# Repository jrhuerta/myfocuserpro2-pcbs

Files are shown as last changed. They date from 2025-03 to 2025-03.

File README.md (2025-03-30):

# myfocuserpro2-pcbs

Custom PCBs for the MyFocuserPro2 project.

There are custom PCBs using an Arduino Nano and a driver with the corresponding [MyFocuerPro2 firmare](https://sourceforge.net/projects/arduinoascomfocuserpro2diy/).

DISCLAIMER: I designed and ordered the PCBs just last night, so I haven’t had the opportunity to test them yet. I’ll confirm their functionality as soon as they arrive. Your reviews and pull requests are welcome. As with any DIY project, please proceed at your own risk.

## ULN2003

This version used with the 28BYJ-48 5V stepper powered directly from USB and a simple ULN2003 driver.
Intended to be used with an OAG or Guidescope, with 2 push bottons to retain the ability to adjust the scope manually.

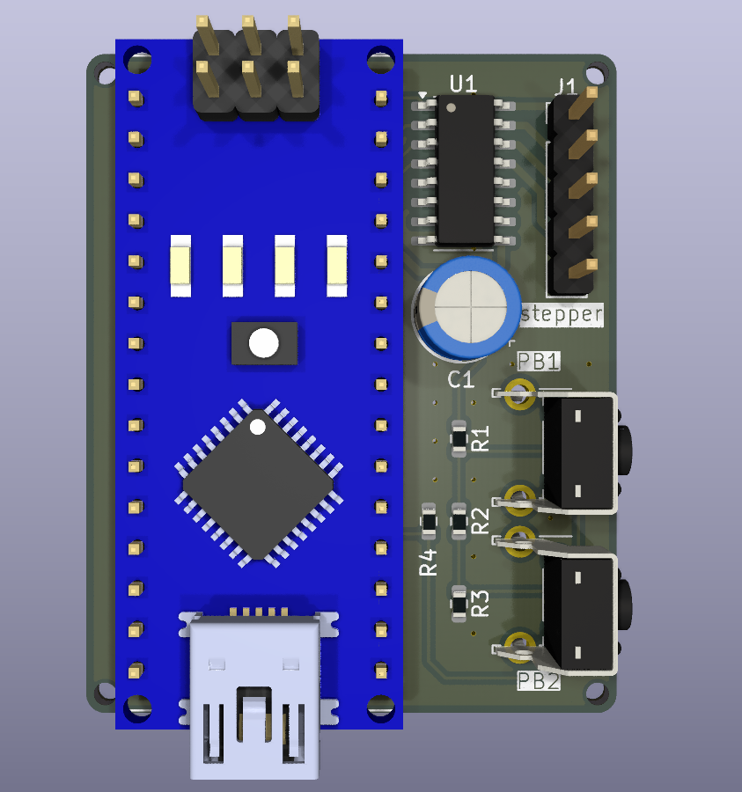
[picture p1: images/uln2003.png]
ULN2003 Driver


## DRV8825

This version is used with a geared Nema17 and external 12V power, intended to handle heavier image trains.
It has the footprint to expand it with a set of push bottons if desired.

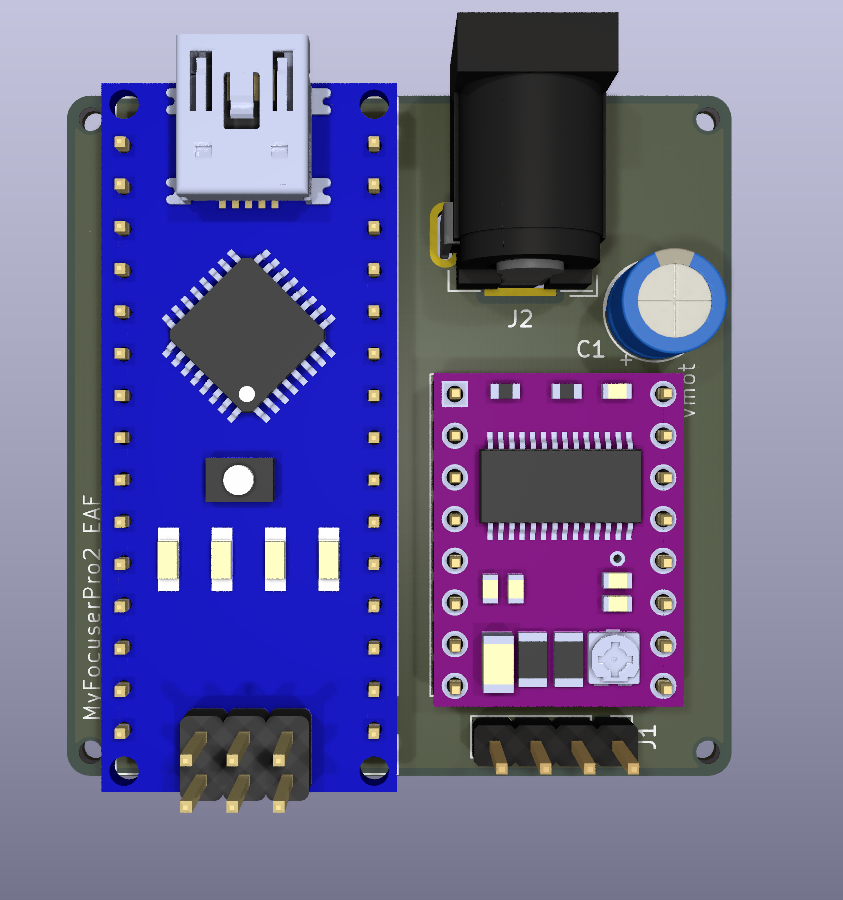
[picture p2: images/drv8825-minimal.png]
DRV8825


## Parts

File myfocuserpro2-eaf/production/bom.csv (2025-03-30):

Designator | Footprint | Quantity | Value | LCSC Part #
A1 | Arduino_Nano | 1 | Arduino_Nano
A2 | Pololu_Breakout-16_15.2x20.3mm | 1 | DRV8825
C1 | CP_Radial_D6.3mm_P2.50mm | 1 | 100uF
J1 | PinHeader_1x04_P2.54mm_Vertical | 1 | Conn_01x04
J2 | BarrelJack_GCT_DCJ200-10-A_Horizontal | 1 | 12V
J3 | PinHeader_1x03_P2.54mm_Vertical | 1 | buttons

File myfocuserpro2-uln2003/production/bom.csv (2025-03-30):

Designator | Footprint | Quantity | Value | LCSC Part #
A1 | Arduino_Nano | 1 | Arduino_Nano
C1 | CP_Radial_D6.3mm_P2.50mm | 1 | 100 uF
J1 | PinHeader_1x05_P2.54mm_Vertical | 1 | Conn_01x05
PB1, PB2 | SW_Tactile_SPST_Angled_PTS645Vx39-2LFS | 2 | SW_Push
R1, R2, R3 | 0603 | 3 | 1.2K | C22765
R4 | 0603 | 1 | 1M | C22935
U1 | SOIC-16_3.9x9.9mm_P1.27mm | 1 | ULN2003A | C7512

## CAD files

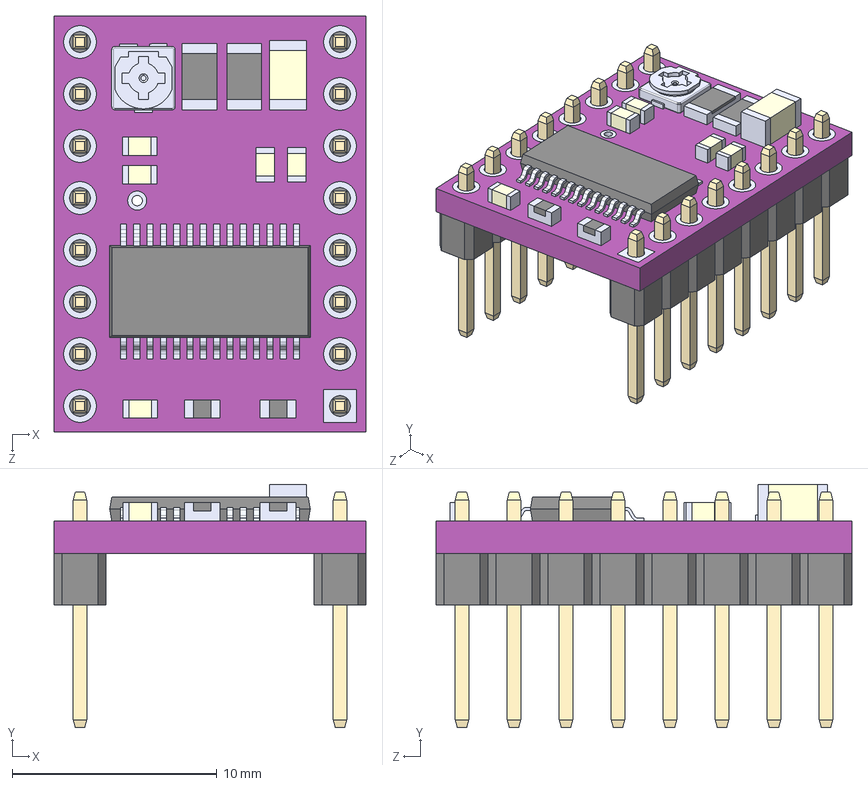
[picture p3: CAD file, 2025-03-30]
myfocuserpro2-eaf/models/DRV8825 STEPPER MOTOR DRIVER CARRIER--3DModel-STEP-1.STEP
15.2 x 11.9 x 20.3 mm

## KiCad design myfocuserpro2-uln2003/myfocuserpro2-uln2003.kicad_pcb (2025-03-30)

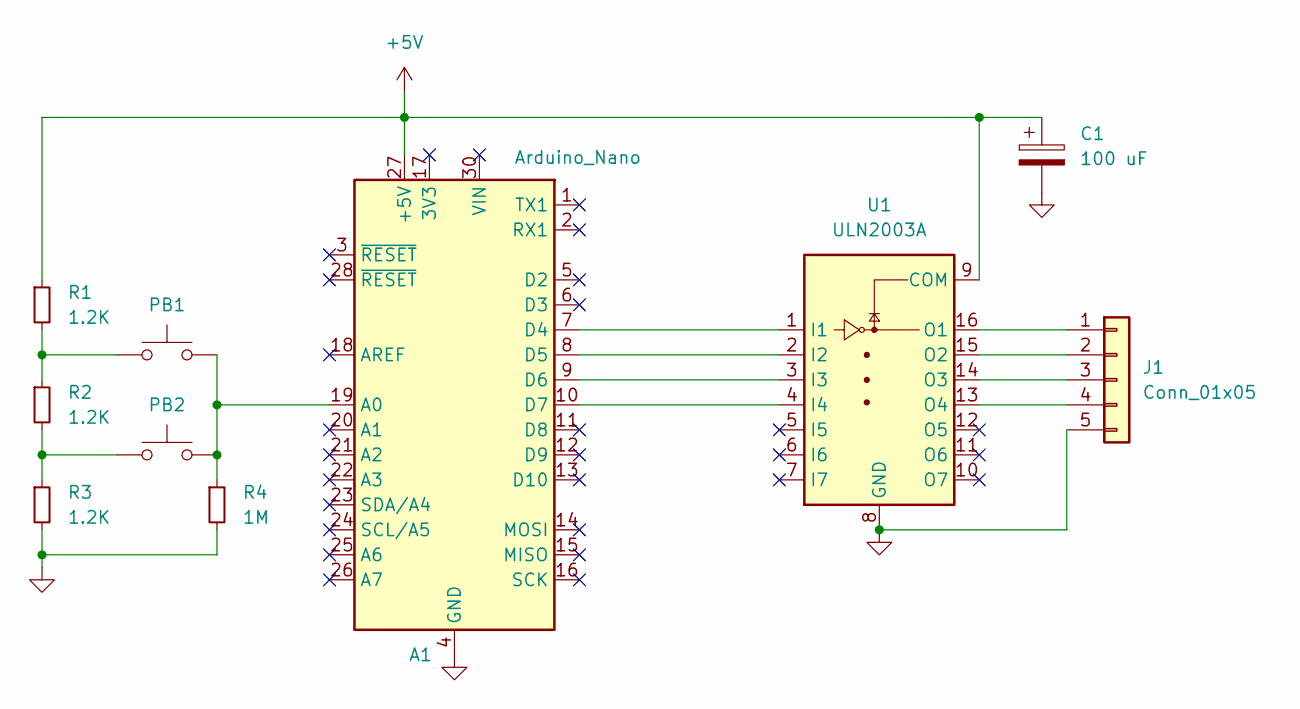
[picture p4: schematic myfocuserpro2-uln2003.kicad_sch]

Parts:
A1: Arduino_Nano
C1: 100 uF; CP_Radial_D6.3mm_P2.50mm
J1: Conn_01x05; PinHeader_1x05_P2.54mm_Vertical
PB1, PB2: SW_Push; SW_Tactile_SPST_Angled_PTS645Vx39-2LFS
R1, R2, R3: 1.2K; R_0603_1608Metric; LCSC C22765
R4: 1M; R_0603_1608Metric; LCSC C22935
U1: ULN2003A; SOIC-16_3.9x9.9mm_P1.27mm; LCSC C7512

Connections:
+5V: A1.27 (+5V), C1.1, R1.1, U1.9 (COM)
GND: A1.4 (GND), A1.29 (GND), C1.2, J1.5, R3.2, R4.2, U1.8 (GND)
unnamed: A1.19 (A0), PB1.2, PB2.2, R4.1
unnamed: A1.7 (D4), U1.1 (I1)
unnamed: A1.8 (D5), U1.2 (I2)
unnamed: A1.9 (D6), U1.3 (I3)
unnamed: A1.10 (D7), U1.4 (I4)
unnamed: J1.1, U1.16 (O1)
unnamed: J1.2, U1.15 (O2)
unnamed: J1.3, U1.14 (O3)
unnamed: J1.4, U1.13 (O4)
unnamed: PB1.1, R1.2, R2.1
unnamed: PB2.1, R2.2, R3.1

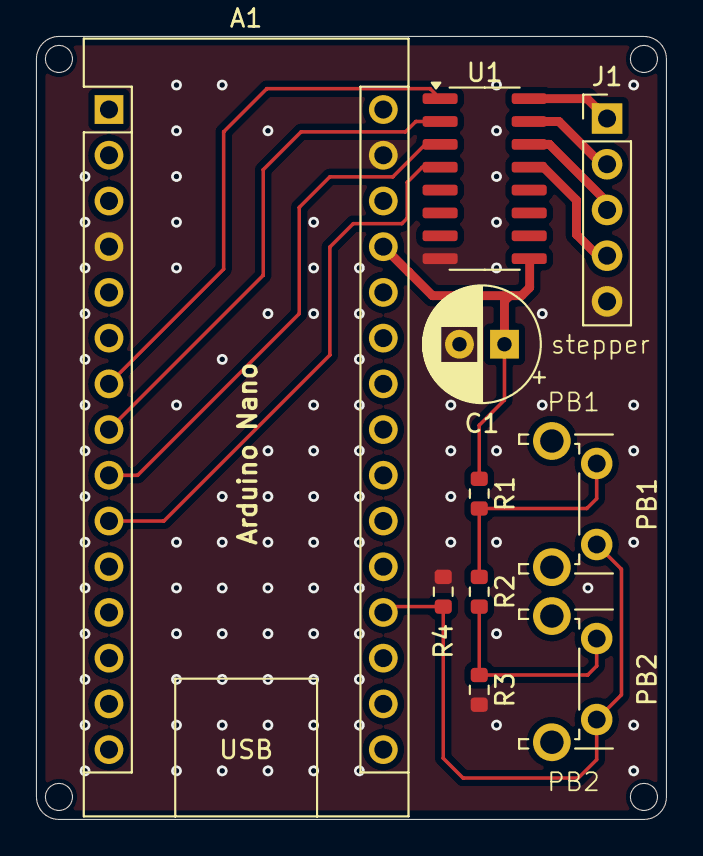
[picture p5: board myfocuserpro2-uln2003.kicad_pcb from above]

Board: 2 copper layers, 35.0 x 43.5 mm, 14 parts (0 on the bottom side), 13 nets.

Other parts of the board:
H1, H2, H3, H4: MountingHole_Pad; MountingHole_1.5mm

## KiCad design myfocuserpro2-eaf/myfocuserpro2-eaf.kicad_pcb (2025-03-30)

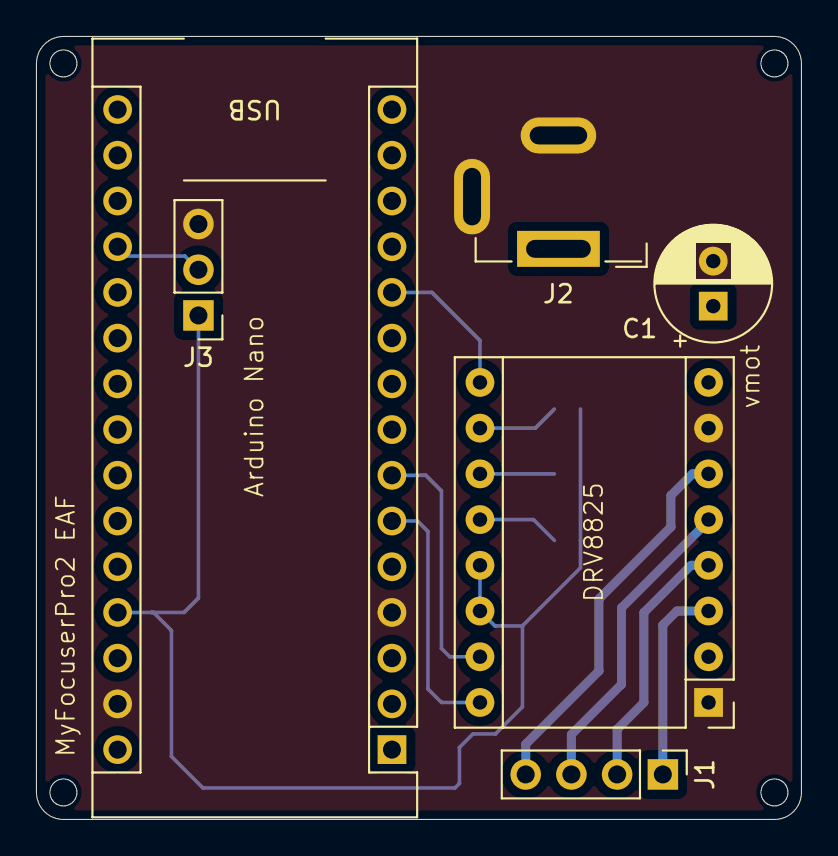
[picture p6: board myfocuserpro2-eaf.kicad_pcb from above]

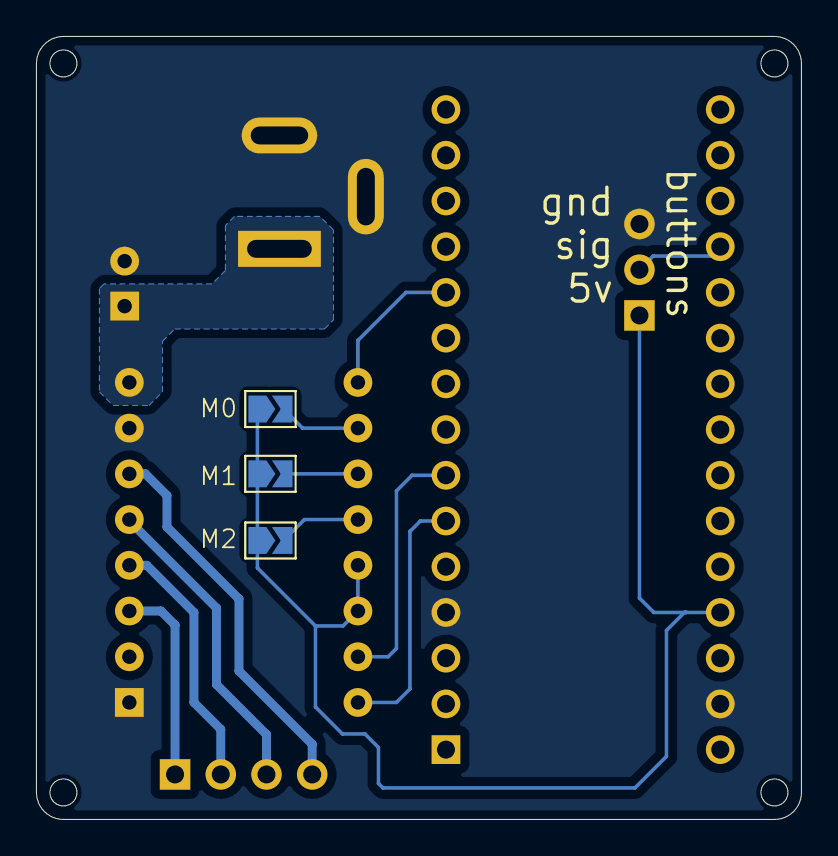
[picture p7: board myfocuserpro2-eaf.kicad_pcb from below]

Board: 2 copper layers, 42.5 x 43.5 mm, 13 parts (3 on the bottom side), 14 nets.

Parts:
A1: Arduino_Nano
A2: DRV8825; Pololu_Breakout-16_15.2x20.3mm
C1: 100uF; CP_Radial_D6.3mm_P2.50mm
H1, H2, H3, H4: MountingHole; MountingHole_1.5mm
J1: Conn_01x04; PinHeader_1x04_P2.54mm_Vertical
J2: 12V; BarrelJack_GCT_DCJ200-10-A_Horizontal
J3: buttons; PinHeader_1x03_P2.54mm_Vertical
JP1, JP2, JP3: SolderJumper_2_Open; SolderJumper-2_P1.3mm_Open_TrianglePad1.0x1.5mm

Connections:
+5V: A1.27 (+5V), A2.13 (~RST), A2.14 (~SLP), J3.1, JP1.1 (A), JP2.1 (A), JP3.1 (A)
/BUTTON: A1.19 (A0), J3.2
GND: A1.4 (GND), A1.29 (GND), A2.1 (GND), A2.7 (GND), C1.2, J2.2, J2.3, J3.3
unnamed: A1.6 (D3), A2.16 (DIR)
unnamed: A1.7 (D4), A2.15 (STEP)
unnamed: A1.11 (D8), A2.9 (~EN)
unnamed: A2.4 (A1), J1.2
unnamed: A2.3 (A2), J1.1
unnamed: A2.5 (B1), J1.3
unnamed: A2.6 (B2), J1.4
unnamed: A2.10 (M0), JP1.2 (B)
unnamed: A2.11 (M1), JP2.2 (B)
unnamed: A2.12 (M2), JP3.2 (B)
unnamed: A2.8 (VMOT), C1.1, J2.1
